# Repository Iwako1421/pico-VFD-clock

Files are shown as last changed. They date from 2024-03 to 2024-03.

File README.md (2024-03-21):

# pico-VFD-clock
simple VFD clock using raspberry pi pico

## 部品表
|基板上の表記|値・部品番号|秋月電子通販コード(旧)|
|:----|:----|:----|
|C1|4.7u|P-08154|
|C2|0.33u|P-08147|
|C3|0.33u|P-08147|
|C4|4.7u|P-08154|
|C5|4.7u|P-08154|
|C6|4.7u|P-08154|
|C7|0.1u|P-15927|
|C8|0.1u|P-15927|
|C9|0.1u|P-15927|
|SW1|SET|P-03647|
|SW2|ADJ|P-03647|
|U1|MAX662|I-01165|
|U2|Raspberry Pi Pico|M-16132|
|U3|UT7500L-25-T92-B-K|I-10268|
|U4|TBD62783A|I-10957|
|U5|TBD62783A|I-10957|
|U6|TBD62783A|I-10957|
|U7|LD8195|付属(名古屋大須・ボントンで入手)|

## 組み立て方
1. 部品表を見ながら部品をはんだ付けします
2. このgithubリポジトリ (https://github.com/Iwako1421/pico-VFD-clock) をzipでダウンロードし、解凍してprogram/VFDclock.uf2を取り出します
3. raspberry pi picoのbootselボタンを押しながらmicroUSBケーブルでPCと接続します
4. raspberry pi picoがストレージとして認識されるので、そこにVFDclock.uf2をドラッグ&ドロップします
5. 時刻を合わせて完成

## 時刻合わせ方法
ADJキーを押すたびに通常表示→時間合わせ→分合わせ→秒合わせ→12時制/24時制切り替え→通常表示と切り替わります。合わせたい項目のモードにADJキーで切り替えて、SETキーを押して調整した後ADJキーで通常表示に戻ってください。

## 電源について
USB-MicroBケーブルで給電してください。コネクタが外れやすいので、ケーブルを抜くときは大きくこじらずにまっすぐ引き抜いてください。

## 注意
VFDはガラス製です。割れやすい (特に突起部分) ので、落としたりぶつけたりしないよう十分ご注意ください。

## 質問等
制作者Twitter (@iwamechatronics) またはEmail (k_iwakura1421@outlook.jp) までご連絡ください。

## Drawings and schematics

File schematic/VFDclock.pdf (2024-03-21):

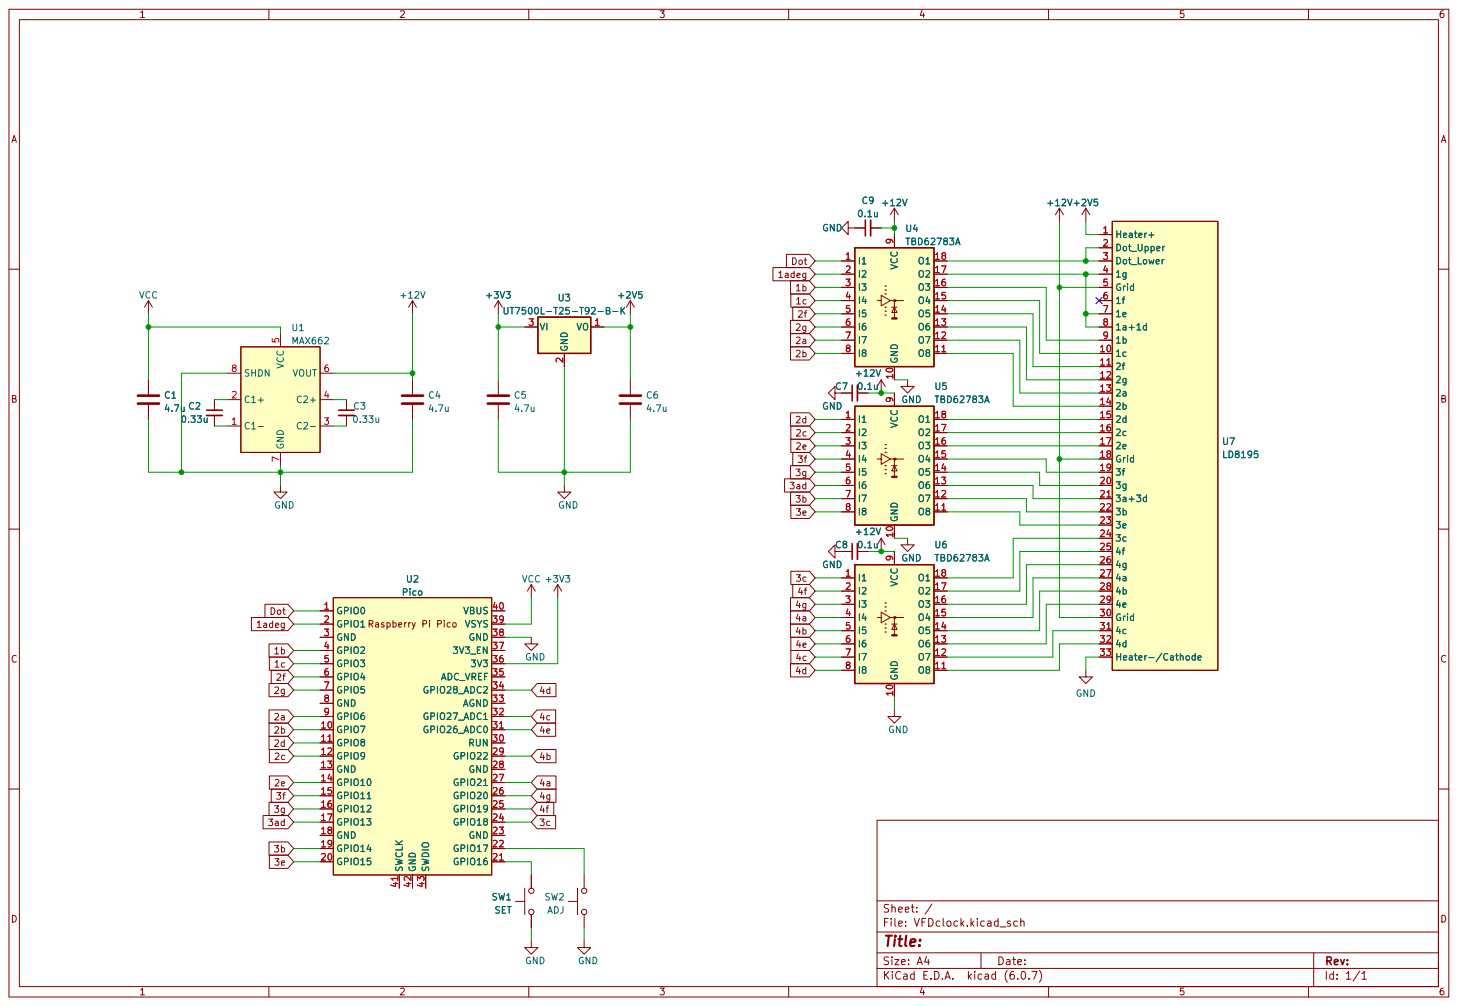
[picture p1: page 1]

1g 4 Grid 5

4f 25
4g 26

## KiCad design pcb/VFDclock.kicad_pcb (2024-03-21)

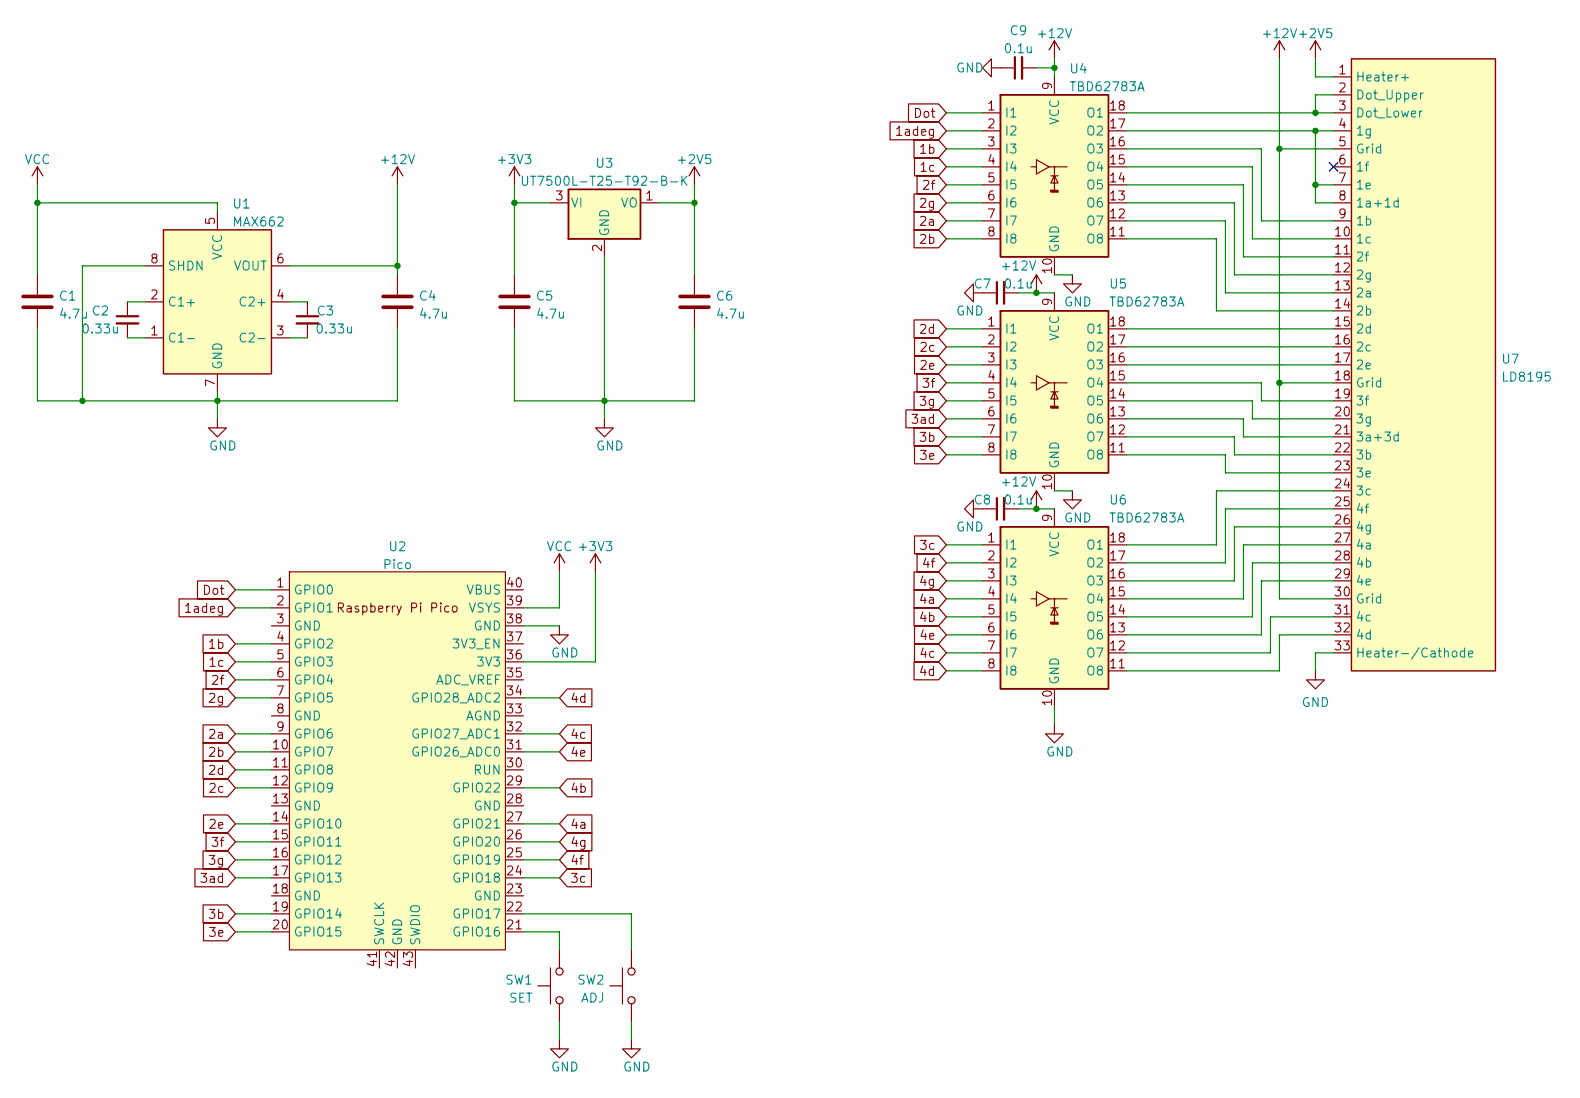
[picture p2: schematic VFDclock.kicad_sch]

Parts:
C1, C4, C5, C6: 4.7u; C_Disc_D5.1mm_W3.2mm_P5.00mm
C2, C3: 0.33u; C_Disc_D5.0mm_W2.5mm_P5.00mm
C7, C8, C9: 0.1u; C_Disc_D5.0mm_W2.5mm_P5.00mm
SW1: SET; SW_PUSH_6mm_H7.3mm
SW2: ADJ; SW_PUSH_6mm_H7.3mm
U1: MAX662; DIP-8_W7.62mm_Socket
U2: Pico; RPi_Pico_SMD_TH
U3: UT7500L-T25-T92-B-K; TO-92_Inline_Wide
U4, U5, U6: TBD62783A; DIP-18_W7.62mm_Socket
U7: LD8195; PinSocket_1x33_P2.54mm_Vertical

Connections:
1adeg: U2.2 (GPIO1), U4.2 (I2)
1b: U2.4 (GPIO2), U4.3 (I3)
1c: U2.5 (GPIO3), U4.4 (I4)
2a: U2.9 (GPIO6), U4.7 (I7)
2b: U2.10 (GPIO7), U4.8 (I8)
2c: U2.12 (GPIO9), U5.2 (I2)
2d: U2.11 (GPIO8), U5.1 (I1)
2e: U2.14 (GPIO10), U5.3 (I3)
2f: U2.6 (GPIO4), U4.5 (I5)
2g: U2.7 (GPIO5), U4.6 (I6)
3ad: U2.17 (GPIO13), U5.6 (I6)
3b: U2.19 (GPIO14), U5.7 (I7)
3c: U2.24 (GPIO18), U6.1 (I1)
3e: U2.20 (GPIO15), U5.8 (I8)
3f: U2.15 (GPIO11), U5.4 (I4)
3g: U2.16 (GPIO12), U5.5 (I5)
4a: U2.27 (GPIO21), U6.4 (I4)
4b: U2.29 (GPIO22), U6.5 (I5)
4c: U2.32 (GPIO27_ADC1), U6.7 (I7)
4d: U2.34 (GPIO28_ADC2), U6.8 (I8)
4e: U2.31 (GPIO26_ADC0), U6.6 (I6)
4f: U2.25 (GPIO19), U6.2 (I2)
4g: U2.26 (GPIO20), U6.3 (I3)
+2V5: C6.1, U3.1 (VO), U7.1 (Heater+)
+3V3: C5.1, U2.36 (3V3), U3.3 (VI)
+12V: C4.1, C7.2, C8.2, C9.2, U1.6 (VOUT), U4.9 (VCC), U5.9 (VCC), U6.9 (VCC), U7.5 (Grid), U7.18 (Grid), U7.30 (Grid)
Dot: U2.1 (GPIO0), U4.1 (I1)
GND: C1.2, C4.2, C5.2, C6.2, C7.1, C8.1, C9.1, SW1.2, SW2.2, U1.7 (GND), U1.8 (SHDN), U2.38 (GND), U3.2 (GND), U4.10 (GND), U5.10 (GND), U6.10 (GND), U7.33 (Heater-/Cathode)
unnamed: C2.1, U1.2 (C1+)
unnamed: C2.2, U1.1 (C1-)
unnamed: C3.1, U1.4 (C2+)
unnamed: C3.2, U1.3 (C2-)
unnamed: U4.11 (O8), U7.14 (2b)
unnamed: U4.12 (O7), U7.13 (2a)
unnamed: U4.13 (O6), U7.12 (2g)
unnamed: U4.14 (O5), U7.11 (2f)
unnamed: U4.15 (O4), U7.10 (1c)
unnamed: U4.16 (O3), U7.9 (1b)
unnamed: U4.17 (O2), U7.4 (1g), U7.7 (1e), U7.8 (1a+1d)
unnamed: U4.18 (O1), U7.2 (Dot_Upper), U7.3 (Dot_Lower)
unnamed: U5.11 (O8), U7.23 (3e)
unnamed: U5.12 (O7), U7.22 (3b)
unnamed: U5.13 (O6), U7.21 (3a+3d)
unnamed: U5.14 (O5), U7.20 (3g)
unnamed: U5.15 (O4), U7.19 (3f)
unnamed: U5.16 (O3), U7.17 (2e)
unnamed: U5.17 (O2), U7.16 (2c)
unnamed: U5.18 (O1), U7.15 (2d)
unnamed: U6.11 (O8), U7.32 (4d)
unnamed: U6.12 (O7), U7.31 (4c)
unnamed: U6.13 (O6), U7.29 (4e)
unnamed: U6.14 (O5), U7.28 (4b)
unnamed: U6.15 (O4), U7.27 (4a)
unnamed: U6.16 (O3), U7.26 (4g)
unnamed: U6.17 (O2), U7.25 (4f)
unnamed: U6.18 (O1), U7.24 (3c)
VCC: C1.1, U1.5 (VCC), U2.39 (VSYS)

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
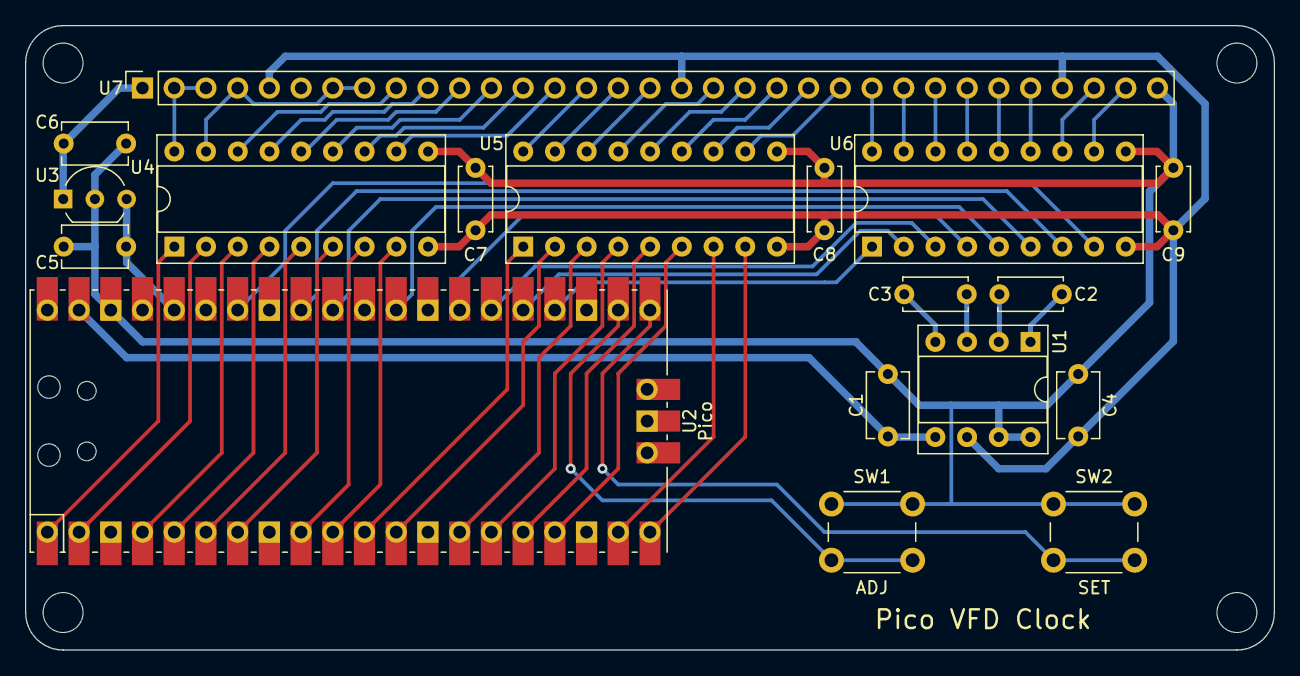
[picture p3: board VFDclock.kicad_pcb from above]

Board: 2 copper layers, 100.0 x 50.0 mm, 18 parts (0 on the bottom side), 59 nets.
